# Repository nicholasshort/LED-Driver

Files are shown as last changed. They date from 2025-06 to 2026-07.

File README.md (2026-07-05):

# LED Driver

A USB-controlled addressable LED strip driver built to illuminate a model car display cabinet. The cabinet houses 500+ 1/43rd scale model cars across 4 vertical sections, each lit by two 120-LED strips (960 LEDs total). Any USB host can control the LEDs. For this appication, the garage includes a Raspberry Pi with a touchscreen running a web interface to send LED colour data.

<table>
  <tr>
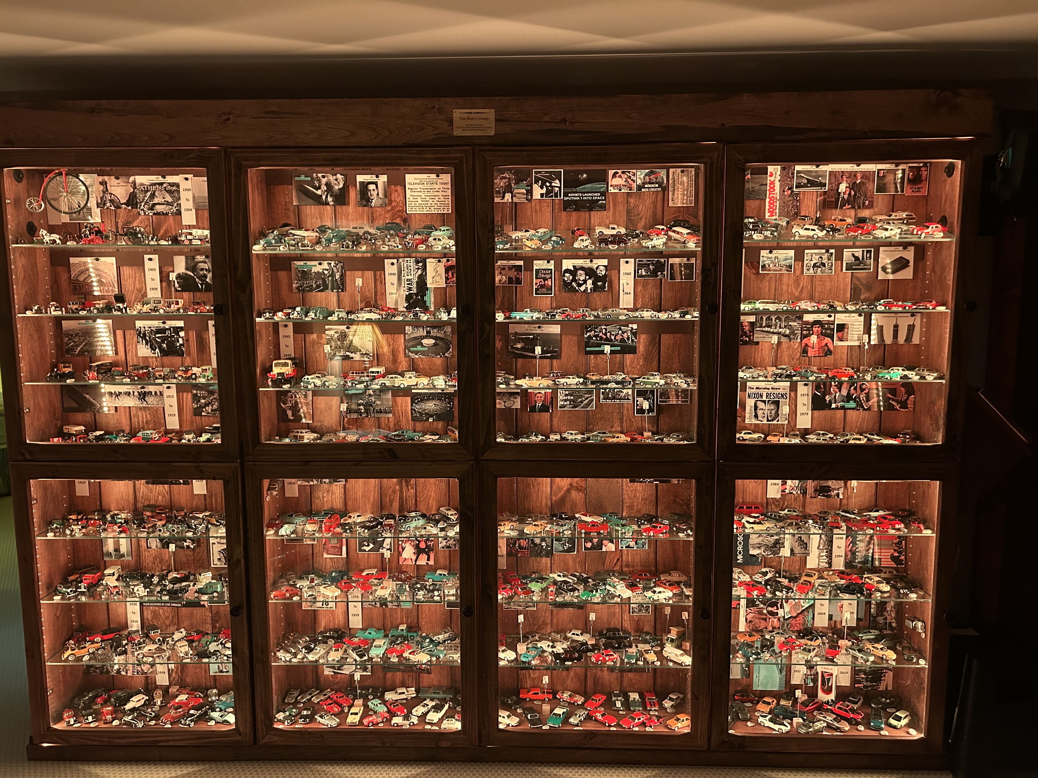
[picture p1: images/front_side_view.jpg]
    <td colspan="3"></td>
  </tr>
  <tr>
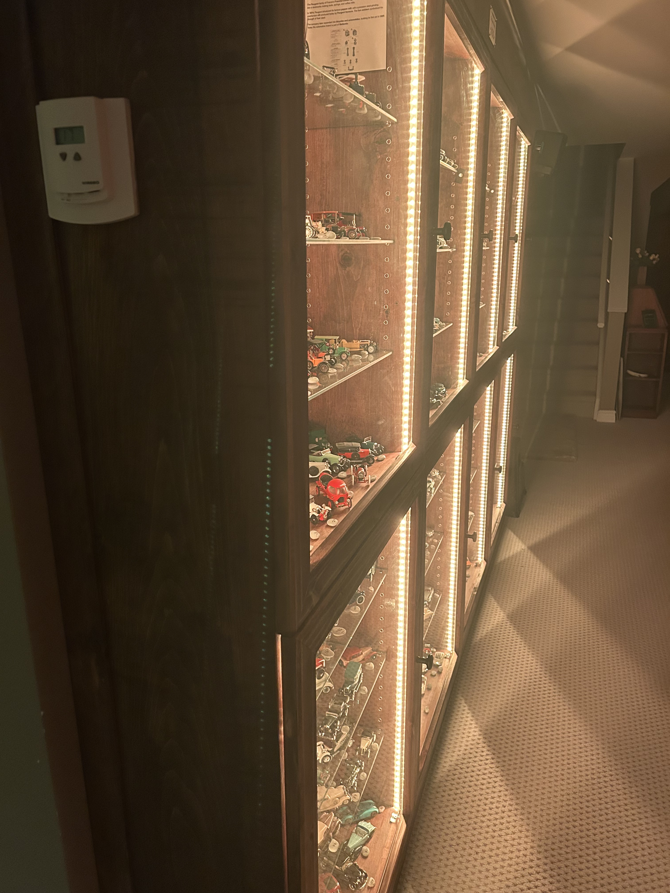
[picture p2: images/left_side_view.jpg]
    <td></td>
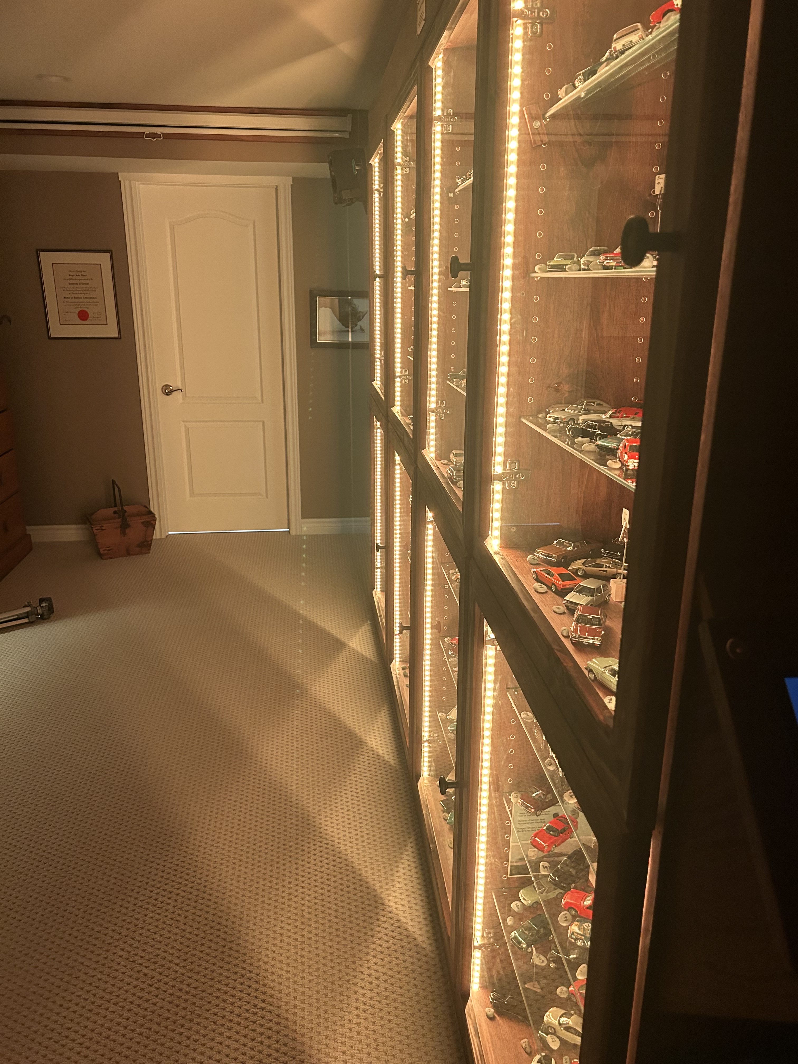
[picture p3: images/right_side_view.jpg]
    <td></td>
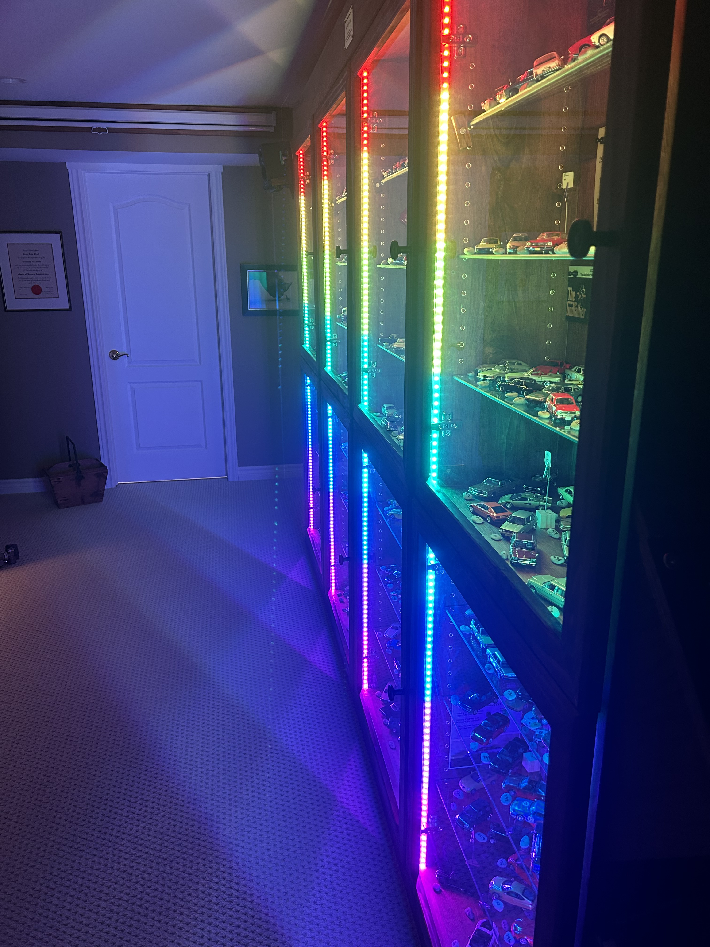
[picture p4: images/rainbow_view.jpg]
    <td></td>
  </tr>
</table>

## Hardware

- **MCU**: STM32F103RGT6 (Cortex-M3 @ 72 MHz, USB FS)
- **LEDs**: 8 × SK6812 addressable RGB strips (120 LEDs each)
- **Interface**: USB-C (CDC virtual COM port)
- **LED Control**: DMA-driven PWM for timing-critical waveform generation
- **PCB**: 4-layer, KiCad

## Repository layout

- `LED-DriverPCB/` — KiCad project (schematics, board, libraries)
- `LED-DriverPCB/Manufacturing/` — Gerbers, BOM, and pick-and-place files
- `LED-Driver-Firmware-RevB/` — STM32CubeIDE project
- `Garage-Files/` — Web control interface and startup audio

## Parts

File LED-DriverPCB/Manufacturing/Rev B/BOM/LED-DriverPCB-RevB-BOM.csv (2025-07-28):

Reference | Value | Footprint | Qty | JLCPCB Part #
H1 | MountingHole |  | 1
H2 | MountingHole |  | 1
H3 | MountingHole |  | 1
H4 | MountingHole |  | 1
H5 | MountingHole |  | 1
H6 | MountingHole |  | 1
H7 | MountingHole |  | 1
H8 | MountingHole |  | 1
J1 | Screw_Terminal_01x03 | 39303037:CONN_5569-03A4&slash_5_MOL | 1
J2 | Screw_Terminal_01x03 | 39303037:CONN_5569-03A4&slash_5_MOL | 1
J3 | Screw_Terminal_01x03 | 39303037:CONN_5569-03A4&slash_5_MOL | 1
J4 | Screw_Terminal_01x03 | 39303037:CONN_5569-03A4&slash_5_MOL | 1
J5 | Screw_Terminal_01x03 | 39303037:CONN_5569-03A4&slash_5_MOL | 1
J6 | Screw_Terminal_01x03 | 39303037:CONN_5569-03A4&slash_5_MOL | 1
J7 | Screw_Terminal_01x03 | 39303037:CONN_5569-03A4&slash_5_MOL | 1
J8 | Screw_Terminal_01x03 | 39303037:CONN_5569-03A4&slash_5_MOL | 1
J12 | Screw_Terminal_01x02 | 26013114:CONN_5569-02A_MOL | 1
J13 | Screw_Terminal_01x02 | 26013114:CONN_5569-02A_MOL | 1
J14 | Screw_Terminal_01x02 | 26013114:CONN_5569-02A_MOL | 1
J15 | Screw_Terminal_01x02 | 26013114:CONN_5569-02A_MOL | 1
J16 | Screw_Terminal_01x02 | 26013114:CONN_5569-02A_MOL | 1
J17 | Screw_Terminal_01x02 | 26013114:CONN_5569-02A_MOL | 1
J18 | Screw_Terminal_01x02 | 26013114:CONN_5569-02A_MOL | 1
J19 | Screw_Terminal_01x02 | 26013114:CONN_5569-02A_MOL | 1
J20 | Conn_ARM_SWD_TagConnect_TC2030 | Connector:Tag-Connect_TC2030-IDC-FP_2x03_P1.27mm_Vertical | 1
TP1 | TestPoint | TestPoint:TestPoint_Pad_1.0x1.0mm | 1
TP2 | TestPoint | TestPoint:TestPoint_Pad_1.0x1.0mm | 1
TP3 | TestPoint | TestPoint:TestPoint_Pad_1.0x1.0mm | 1
TP4 | TestPoint | TestPoint:TestPoint_Pad_1.0x1.0mm | 1
TP5 | TestPoint | TestPoint:TestPoint_Pad_1.0x1.0mm | 1
TP6 | TestPoint | TestPoint:TestPoint_Pad_1.0x1.0mm | 1
TP7 | TestPoint | TestPoint:TestPoint_Pad_1.0x1.0mm | 1
TP8 | TestPoint | TestPoint:TestPoint_Pad_1.0x1.0mm | 1
C3 | 100n | Capacitor_SMD:C_0603_1608Metric | 1 | C1590
C4 | 100n | Capacitor_SMD:C_0603_1608Metric | 1 | C1590
C5 | 100n | Capacitor_SMD:C_0603_1608Metric | 1 | C1590
C6 | 100n | Capacitor_SMD:C_0603_1608Metric | 1 | C1590
C7 | 100n | Capacitor_SMD:C_0603_1608Metric | 1 | C1590
C8 | 100n | Capacitor_SMD:C_0603_1608Metric | 1 | C1590
C10 | 100n | Capacitor_SMD:C_0603_1608Metric | 1 | C1590
C16 | 100n | Capacitor_SMD:C_0603_1608Metric | 1 | C1590
U3 | AMS1117-3.3 | Package_TO_SOT_SMD:SOT-223-3_TabPin2 | 1 | C6186
U4 | USBLC6-2SC6 | Package_TO_SOT_SMD:SOT-23-6 | 1 | C7519
U5 | STM32F103RGTx | Package_QFP:LQFP-64_10x10mm_P0.5mm | 1 | C8317
R6 | 1k | Resistor_SMD:R_0402_1005Metric | 1 | C11702
C9 | 10u | Capacitor_SMD:C_0805_2012Metric | 1 | C15850
C11 | 10u | Capacitor_SMD:C_0805_2012Metric | 1 | C15850
R8 | 0R | Resistor_SMD:R_0603_1608Metric | 1 | C21189
R9 | 0R | Resistor_SMD:R_0603_1608Metric | 1 | C21189
R10 | 0R | Resistor_SMD:R_0603_1608Metric | 1 | C21189
R11 | 0R | Resistor_SMD:R_0603_1608Metric | 1 | C21189
R12 | 0R | Resistor_SMD:R_0603_1608Metric | 1 | C21189
R13 | 0R | Resistor_SMD:R_0603_1608Metric | 1 | C21189
R14 | 0R | Resistor_SMD:R_0603_1608Metric | 1 | C21189
R15 | 0R | Resistor_SMD:R_0603_1608Metric | 1 | C21189
R5 | 1.5k | Resistor_SMD:R_0603_1608Metric | 1 | C22843
R2 | 5.1k | Resistor_SMD:R_0603_1608Metric | 1 | C23186
R3 | 5.1k | Resistor_SMD:R_0603_1608Metric | 1 | C23186
R1 | 10k | Resistor_SMD:R_0603_1608Metric | 1 | C25804
R4 | 10k | Resistor_SMD:R_0603_1608Metric | 1 | C25804
R7 | 10k | Resistor_SMD:R_0603_1608Metric | 1 | C25804
C12 | 22u | Capacitor_SMD:C_0805_2012Metric | 1 | C45783
C1 | 10p | Capacitor_SMD:C_0402_1005Metric | 1 | C161145
C2 | 10p | Capacitor_SMD:C_0402_1005Metric | 1 | C161145
J9 | USB_C_Receptacle_USB2.0_16P | Connector_USB:USB_C_Receptacle_HRO_TYPE-C-31-M-12 | 1 | C165948
X1 | 8MHz | Crystal:Crystal_SMD_3225-4Pin_3.2x2.5mm | 1 | C400090
U1 | 74AHCT244 | Package_SO:TSSOP-20_4.4x6.5mm_P0.65mm | 1 | C484743
D1 | LED | LED_SMD:LED_0603_1608Metric | 1 | C5123548

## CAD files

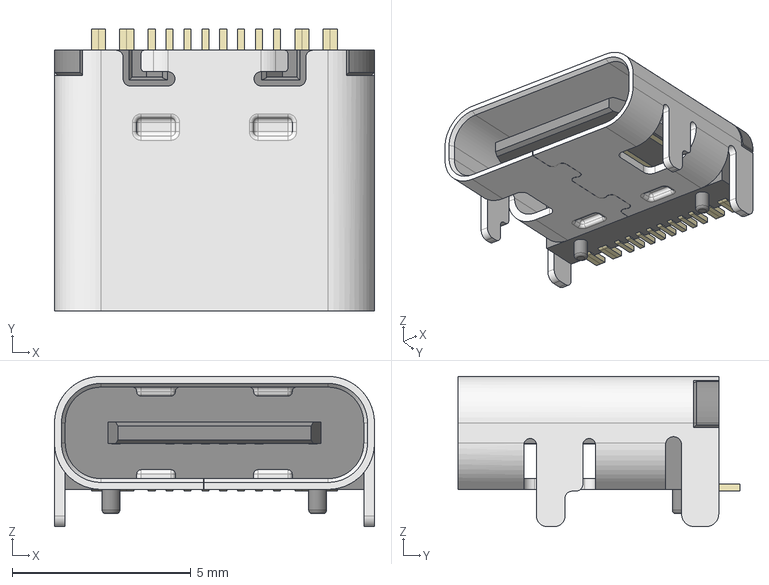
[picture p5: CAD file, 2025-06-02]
LED-DriverPCB/Components/Miscellaneous 3D Models/HRO_TYPE-C-31-M-12.step
8.95 x 7.90 x 4.20 mm

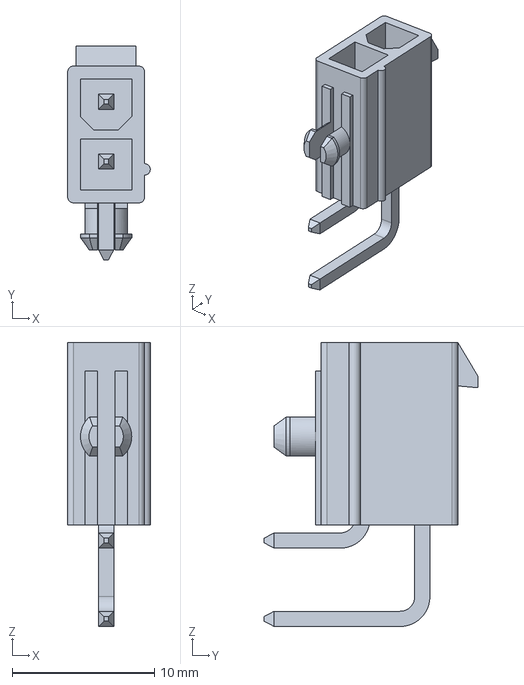
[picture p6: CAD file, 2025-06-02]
LED-DriverPCB/Components/26013114/026013114.stp
5.80 x 15.0 x 19.9 mm

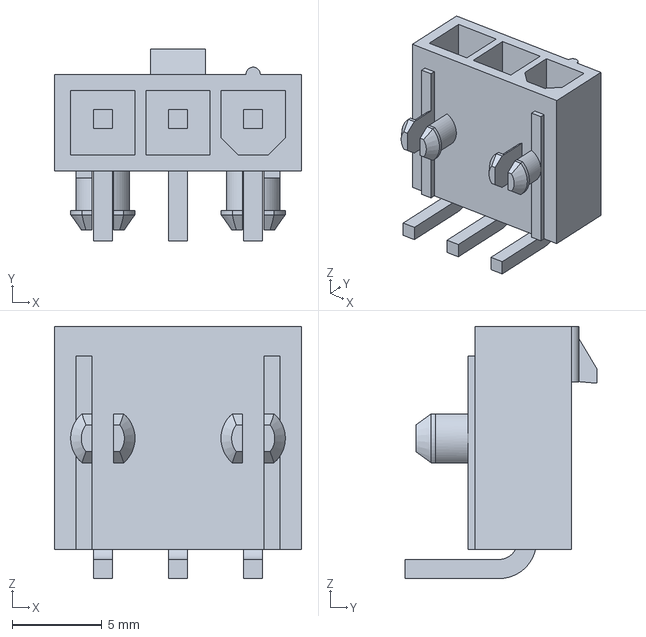
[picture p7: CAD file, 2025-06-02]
LED-DriverPCB/Components/39303037/039303037.stp
13.8 x 10.7 x 14.1 mm

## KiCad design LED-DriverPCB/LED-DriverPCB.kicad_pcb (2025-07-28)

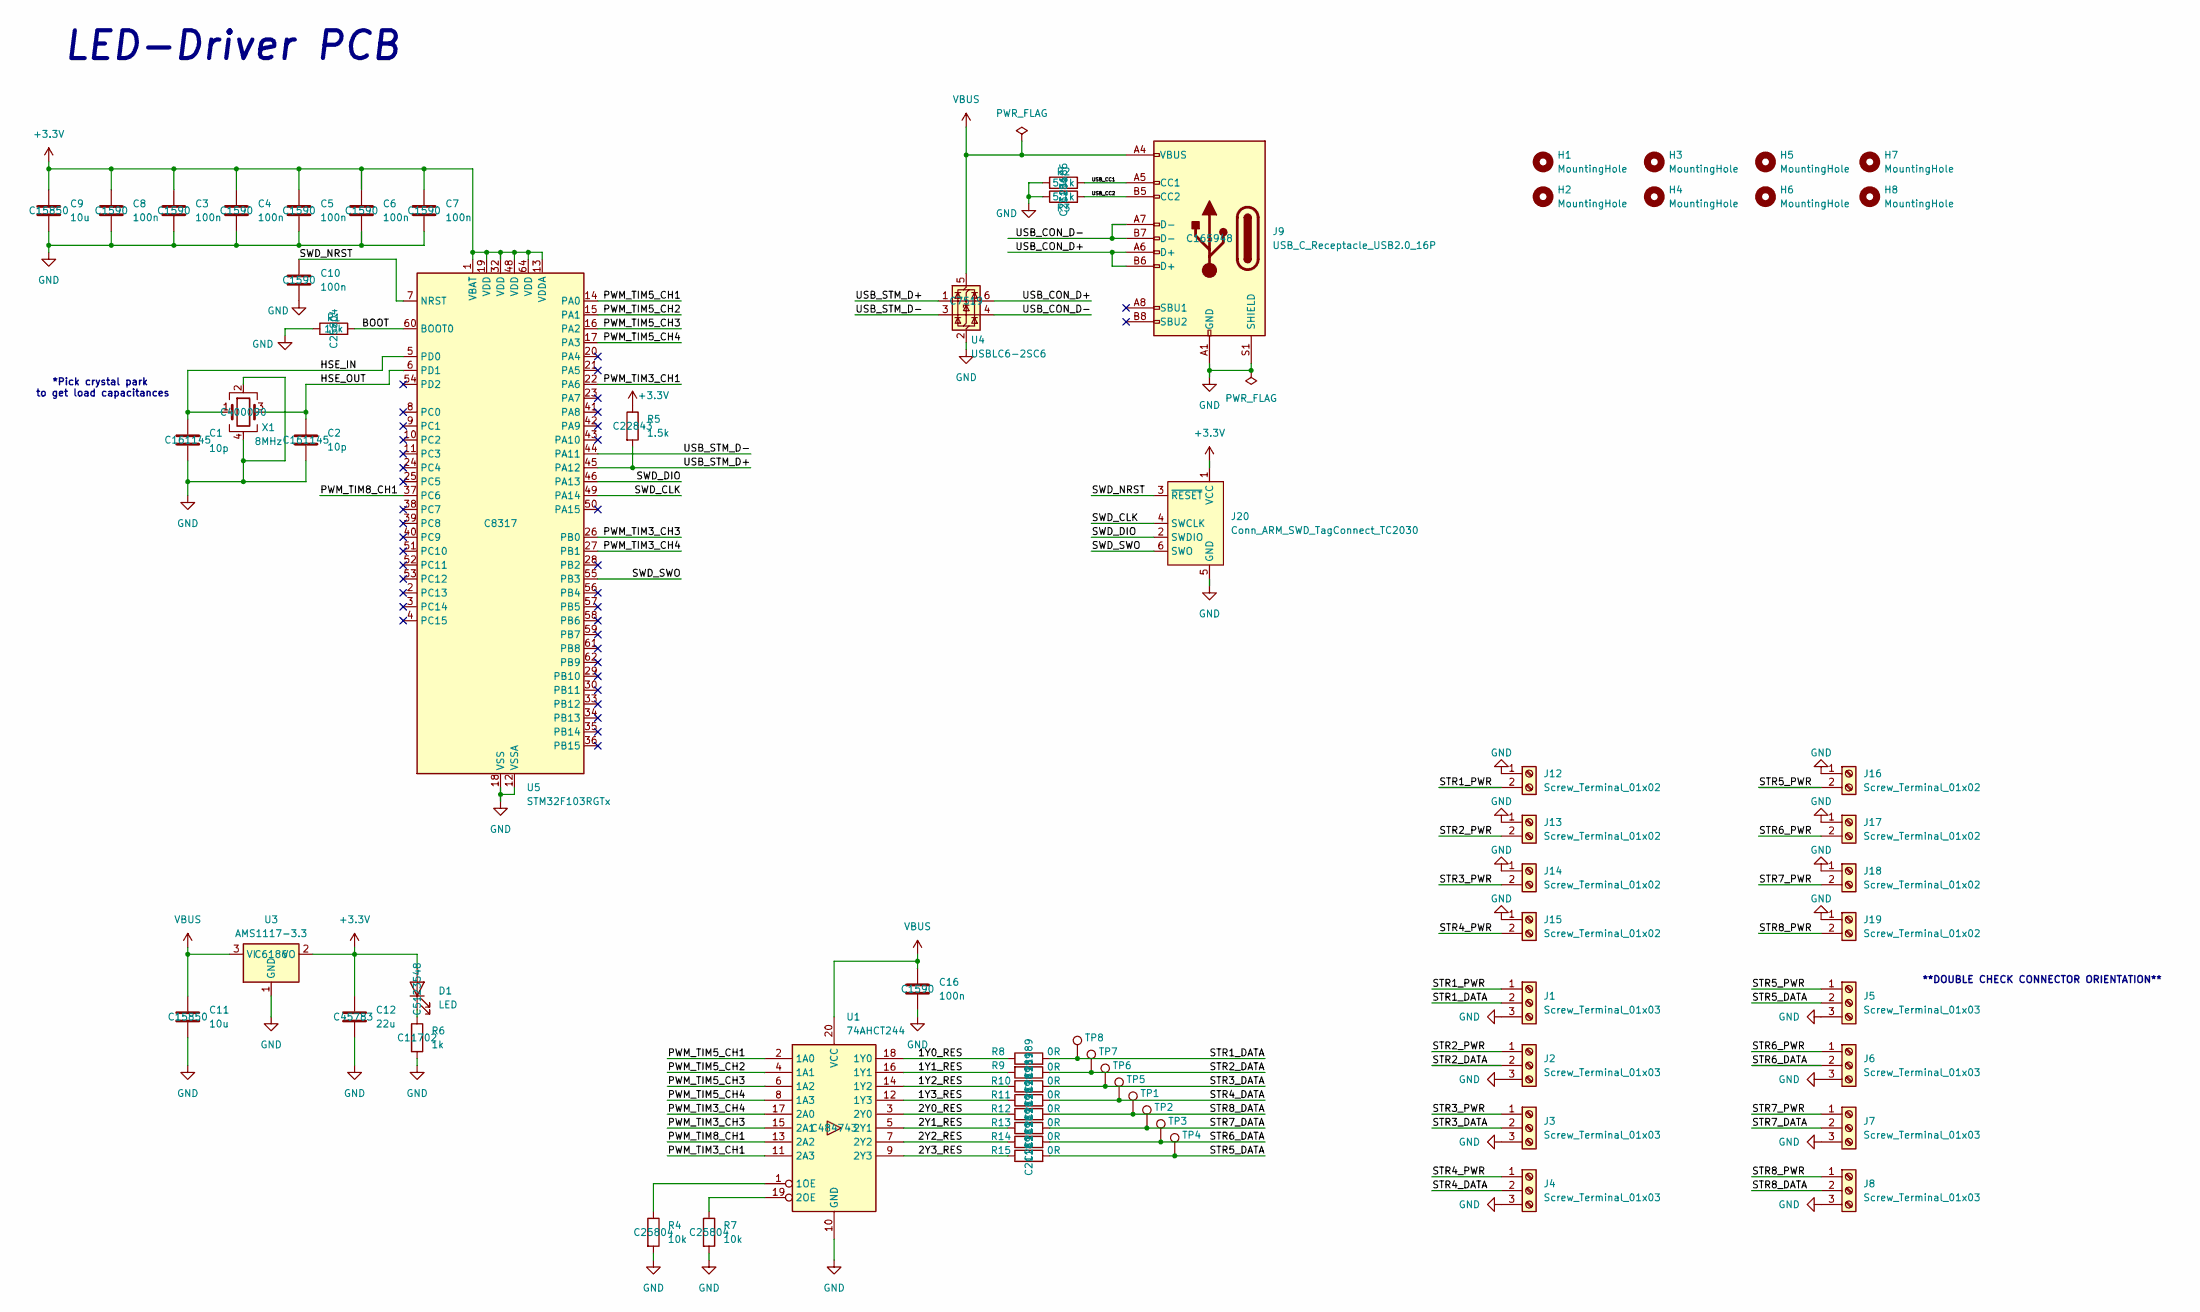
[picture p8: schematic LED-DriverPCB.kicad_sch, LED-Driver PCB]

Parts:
C1, C2: 10p; C_0402_1005Metric; JLCPCB Part # C161145
C3, C4, C5, C6, C7, C8, C10, C16: 100n; C_0603_1608Metric; JLCPCB Part # C1590
C9, C11: 10u; C_0805_2012Metric; JLCPCB Part # C15850
C12: 22u; C_0805_2012Metric; JLCPCB Part # C45783
D1: LED; LED_0603_1608Metric; JLCPCB Part # C5123548
H1, H2, H3, H4, H5, H6, H7, H8: MountingHole
J1, J2, J3, J4, J5, J6, J7, J8: Screw_Terminal_01x03; CONN_5569-03A4&slash_5_MOL
J9: USB_C_Receptacle_USB2.0_16P; USB_C_Receptacle_HRO_TYPE-C-31-M-12; JLCPCB Part # C165948
J12, J13, J14, J15, J16, J17, J18, J19: Screw_Terminal_01x02; CONN_5569-02A_MOL
J20: Conn_ARM_SWD_TagConnect_TC2030; Tag-Connect_TC2030-IDC-FP_2x03_P1.27mm_Vertical
R1, R4, R7: 10k; R_0603_1608Metric; JLCPCB Part # C25804
R2, R3: 5.1k; R_0603_1608Metric; JLCPCB Part # C23186
R5: 1.5k; R_0603_1608Metric; JLCPCB Part # C22843
R6: 1k; R_0402_1005Metric; JLCPCB Part # C11702
R8, R9, R10, R11, R12, R13, R14, R15: 0R; R_0603_1608Metric; JLCPCB Part # C21189
TP1, TP2, TP3, TP4, TP5, TP6, TP7, TP8: TestPoint; TestPoint_Pad_1.0x1.0mm
U1: 74AHCT244; TSSOP-20_4.4x6.5mm_P0.65mm; JLCPCB Part # C484743
U3: AMS1117-3.3; SOT-223-3_TabPin2; JLCPCB Part # C6186
U4: USBLC6-2SC6; SOT-23-6; JLCPCB Part # C7519
U5: STM32F103RGTx; LQFP-64_10x10mm_P0.5mm; JLCPCB Part # C8317
X1: 8MHz; Crystal_SMD_3225-4Pin_3.2x2.5mm; JLCPCB Part # C400090

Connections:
+3.3V: C3.1, C4.1, C5.1, C6.1, C7.1, C8.1, C9.1, C12.1, D1.2 (A), J20.1 (VCC), R5.1, U3.2 (VO), U5.1 (VBAT), U5.13 (VDDA), U5.19 (VDD), U5.32 (VDD), U5.48 (VDD), U5.64 (VDD)
/1Y0_RES: R8.1, U1.18 (1Y0)
/1Y1_RES: R9.2, U1.16 (1Y1)
/1Y2_RES: R10.1, U1.14 (1Y2)
/1Y3_RES: R11.1, U1.12 (1Y3)
/2Y0_RES: R12.1, U1.3 (2Y0)
/2Y1_RES: R13.1, U1.5 (2Y1)
/2Y2_RES: R14.1, U1.7 (2Y2)
/2Y3_RES: R15.1, U1.9 (2Y3)
/BOOT: R1.2, U5.60 (BOOT0)
/HSE_IN: C1.1, U5.5 (PD0), X1.1
/HSE_OUT: C2.1, U5.6 (PD1), X1.3
/PWM_TIM3_CH1: U1.11 (2A3), U5.22 (PA6)
/PWM_TIM3_CH3: U1.15 (2A1), U5.26 (PB0)
/PWM_TIM3_CH4: U1.17 (2A0), U5.27 (PB1)
/PWM_TIM5_CH1: U1.2 (1A0), U5.14 (PA0)
/PWM_TIM5_CH2: U1.4 (1A1), U5.15 (PA1)
/PWM_TIM5_CH3: U1.6 (1A2), U5.16 (PA2)
/PWM_TIM5_CH4: U1.8 (1A3), U5.17 (PA3)
/PWM_TIM8_CH1: U1.13 (2A2), U5.37 (PC6)
/STR1_DATA: J1.2, R8.2, TP8.1
/STR1_PWR: J1.1, J12.2
/STR2_DATA: J2.2, R9.1, TP7.1
/STR2_PWR: J2.1, J13.2
/STR3_DATA: J3.2, R10.2, TP6.1
/STR3_PWR: J3.1, J14.2
/STR4_DATA: J4.2, R11.2, TP5.1
/STR4_PWR: J4.1, J15.2
/STR5_DATA: J5.2, R15.2, TP4.1
/STR5_PWR: J5.1, J16.2
/STR6_DATA: J6.2, R14.2, TP3.1
/STR6_PWR: J6.1, J17.2
/STR7_DATA: J7.2, R13.2, TP2.1
/STR7_PWR: J7.1, J18.2
/STR8_DATA: J8.2, R12.2, TP1.1
/STR8_PWR: J8.1, J19.2
/SWD_CLK: J20.4 (SWCLK), U5.49 (PA14)
/SWD_DIO: J20.2 (SWDIO), U5.46 (PA13)
/SWD_NRST: C10.1, J20.3 (~RESET), U5.7 (NRST)
/SWD_SWO: J20.6 (SWO), U5.55 (PB3)
/USB_CC1: J9.A5 (CC1), R2.2
/USB_CC2: J9.B5 (CC2), R3.2
/USB_CON_D+: J9.A6 (D+), J9.B6 (D+), U4.6 (I/O1)
/USB_CON_D-: J9.A7 (D-), J9.B7 (D-), U4.4 (I/O2)
/USB_STM_D+: R5.2, U4.1 (I/O1), U5.45 (PA12)
/USB_STM_D-: U4.3 (I/O2), U5.44 (PA11)
GND: C1.2, C2.2, C3.2, C4.2, C5.2, C6.2, C7.2, C8.2, C9.2, C10.2, C11.2, C12.2, C16.2, J1.3, J2.3, J3.3, J4.3, J5.3, J6.3, J7.3, J8.3, J9.A1 (GND), J9.A12 (GND), J9.B1 (GND), J9.B12 (GND), J9.S1 (SHIELD), J12.1, J13.1, J14.1, J15.1, J16.1, J17.1, J18.1, J19.1, J20.5 (GND), R1.1, R2.1, R3.1, R4.2, R6.2, R7.2, U1.10 (GND), U3.1 (GND), U4.2 (GND), U5.12 (VSSA), U5.18 (VSS), U5.31 (VSS), U5.47 (VSS), U5.63 (VSS), X1.2, X1.4
unnamed: D1.1 (K), R6.1
unnamed: R4.1, U1.1 (1OE)
unnamed: R7.1, U1.19 (2OE)
VBUS: C11.1, C16.1, J9.A4 (VBUS), J9.A9 (VBUS), J9.B4 (VBUS), J9.B9 (VBUS), U1.20 (VCC), U3.3 (VI), U4.5 (VBUS)

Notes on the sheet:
LED-Driver PCB
*Pick crystal park to get load capacitances
**DOUBLE CHECK CONNECTOR ORIENTATION**

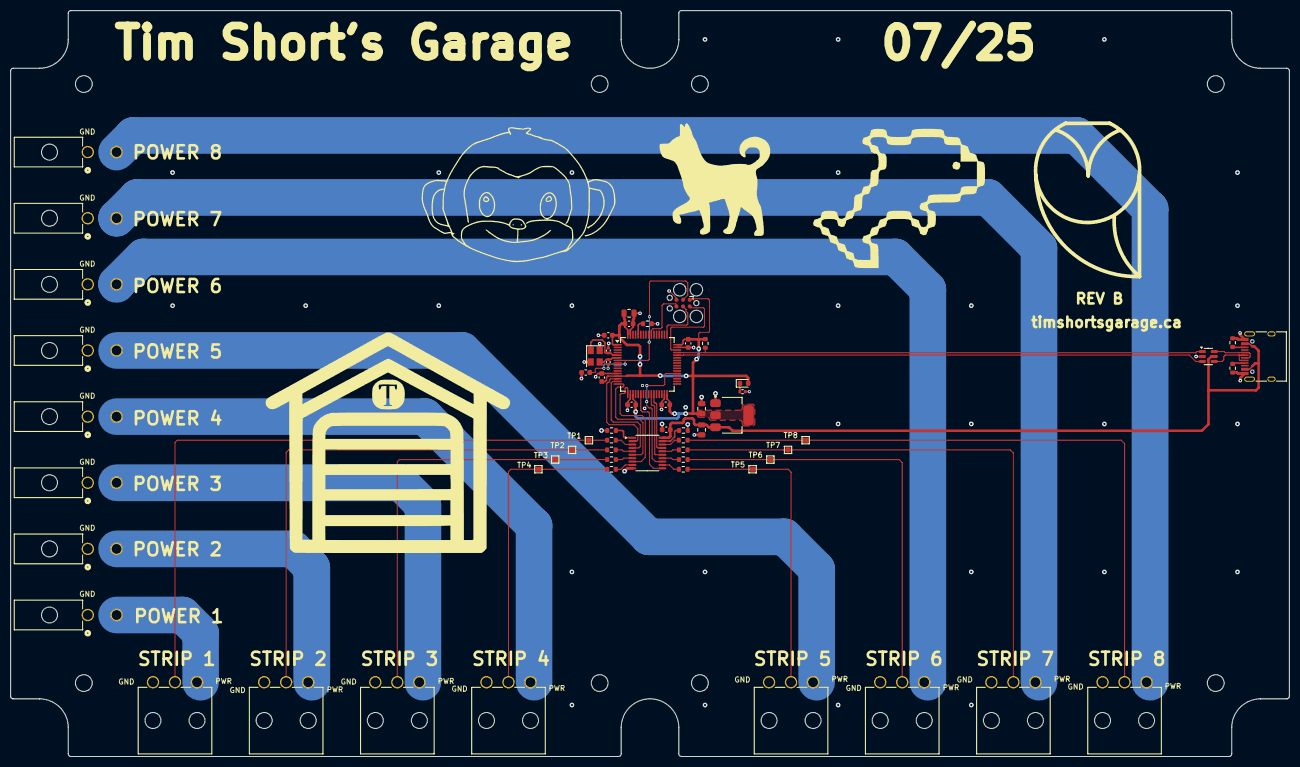
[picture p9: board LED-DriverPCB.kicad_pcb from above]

Board: 4 copper layers, 244.0 x 142.3 mm, 68 parts (0 on the bottom side), 51 nets.

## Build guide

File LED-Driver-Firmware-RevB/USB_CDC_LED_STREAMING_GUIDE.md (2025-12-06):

# USB CDC LED Frame Streaming Protocol - Integration Guide

## Overview

This implementation provides a complete USB CDC-based LED frame streaming system for driving 8 parallel SK6812 LED strips (120 LEDs each) from a Raspberry Pi host to an STM32F1 microcontroller.

**Key Features:**
- 30 FPS RGB LED frame streaming over USB CDC Virtual COM Port
- Robust framing protocol with checksum validation
- Double-buffered frame reception (no tearing)
- Non-blocking USB receive handling
- Streaming parser handles arbitrary USB packet chunking
- Total throughput: ~864 KB/s (2880 bytes × 30 fps + protocol overhead)

---

## Architecture

### Hardware
- **MCU:** STM32F103 @ 72 MHz
- **USB:** Full Speed Device (12 Mbps), CDC class
- **LEDs:** 8 strips × 120 LEDs × 3 bytes (RGB) = 2880 bytes per frame
- **Host:** Raspberry Pi (or any Linux system with USB)

### Software Components

#### STM32 Firmware
1. **usb_protocol.c/h** - Protocol parser and double buffering
2. **usbd_cdc_if.c** - USB CDC receive callback integration
3. **main.c** - Main loop with LED update logic
4. **LEDStrip_Manager** - Existing LED driver (your implementation)
5. **SK6812-LEDStrip** - Existing SK6812 driver (your implementation)

#### Raspberry Pi Host
1. **host_send_led_frames.py** - Python script for streaming frames at 30 FPS

---

## Protocol Specification

### Frame Structure

Every frame consists of:
1. **Header (9 bytes)** - Fixed format
2. **Payload (2880 bytes)** - RGB data for all LEDs

### Header Format

```c
#pragma pack(push, 1)
typedef struct {
    uint8_t  sof1;       // 0xAA - Start of frame marker
    uint8_t  sof2;       // 0x55 - Start of frame marker
    uint8_t  version;    // 0x01 - Protocol version
    uint8_t  type;       // 0x01 - Frame type (full LED frame)
    uint16_t length;     // 2880 - Payload length (little endian)
    uint16_t frame_id;   // Frame counter (little endian, wraps at 65535)
    uint8_t  checksum;   // 8-bit sum of payload bytes mod 256
} frame_hdr_t;
#pragma pack(pop)
```

**Total frame size:** 9 + 2880 = 2889 bytes

### Payload Layout

The 2880-byte payload contains RGB data for all LEDs:

```
Strip 0: [LED 0..119] = R,G,B, R,G,B, ... (360 bytes)
Strip 1: [LED 0..119] = R,G,B, R,G,B, ... (360 bytes)
...
Strip 7: [LED 0..119] = R,G,B, R,G,B, ... (360 bytes)
```

**Memory mapping:**
- Strip N, LED M: `payload[N * 360 + M * 3 + {0=R, 1=G, 2=B}]`

### Checksum Calculation

```c
uint8_t checksum = 0;
for (int i = 0; i < 2880; i++) {
    checksum += payload[i];
}
checksum = checksum & 0xFF;
```

---

## STM32 Implementation Details

### State Machine

The protocol parser implements a streaming state machine in `usb_protocol.c`:

```
RX_WAIT_SOF1 → Wait for 0xAA
     ↓
RX_WAIT_SOF2 → Wait for 0x55
     ↓
RX_READ_HEADER → Read remaining 7 header bytes
     ↓
RX_READ_PAYLOAD → Read 2880 payload bytes into pending_frame
     ↓
Validate checksum → Swap buffers if valid → RX_WAIT_SOF1
```

**Key features:**
- Handles arbitrary USB packet chunking (e.g., 64-byte CDC packets)
- Validates SOF bytes, version, type, and length
- Computes and verifies 8-bit checksum
- Atomically swaps double buffers using interrupt disable/enable

### Double Buffering

Two 2880-byte buffers:
- **active_frame** - Currently displayed (read by main loop)
- **pending_frame** - Being written by USB receive (write by parser)

When a valid frame is received:
1. Checksum is validated
2. Pointers are swapped atomically (`__disable_irq()` / `__enable_irq()`)
3. `new_frame_ready` flag is set
4. Main loop detects flag and sends active_frame to LEDs

This prevents tearing and ensures the main loop always sees complete, validated frames.

### USB Receive Flow

```c
// In usbd_cdc_if.c
static int8_t CDC_Receive_FS(uint8_t* Buf, uint32_t *Len)
{
    // Feed bytes to streaming parser (non-blocking)
    protocol_feed_bytes(Buf, *Len);

    // Re-arm USB endpoint immediately
    USBD_CDC_SetRxBuffer(&hUsbDeviceFS, &Buf[0]);
    USBD_CDC_ReceivePacket(&hUsbDeviceFS);

    return USBD_OK;
}
```

**Critical:** No blocking operations in `CDC_Receive_FS()`. LED updates happen in main loop.

### Main Loop Integration

```c
// In main.c
while (1)
{
    if (protocol_new_frame_ready())
    {
        const uint8_t *frame = protocol_get_active_frame();

        // Copy frame data to LED driver buffers
        for (uint8_t strip = 0; strip < 8; strip++)
        {
            for (uint16_t led = 0; led < 120; led++)
            {
                uint16_t offset = strip * 360 + led * 3;
                SK6812_SetColour(handle, led,
                    frame[offset + 0],  // R
                    frame[offset + 1],  // G
                    frame[offset + 2]); // B
            }
        }

        // Send to LEDs (blocking)
        for (uint8_t strip = 0; strip < 8; strip++)
            SK6812_Update(LEDStrip_Manager_Get_Strip_Handle(strip));

        protocol_ack_frame();
    }

    HAL_Delay(1);
}
```

---

## Raspberry Pi Host Implementation

### Requirements

```bash
pip install pyserial
```

### Running the Script

```bash
# Default device (/dev/ttyACM0)
python3 host_send_led_frames.py

# Custom device
python3 host_send_led_frames.py /dev/ttyACM1
```

### Animation Modes

Edit `animation_mode` variable in `main()`:

- `'rainbow'` - Moving rainbow pattern
- `'chaser'` - Colored dots chasing down each strip
- `'solid'` - Breathing blue effect

### Frame Generation

The Python script:
1. Generates 2880-byte RGB payload
2. Calculates checksum
3. Builds 9-byte header with `struct.pack('<BBBBHHB', ...)`
4. Sends header + payload over serial
5. Sleeps to maintain ~30 FPS

**Actual timing:** The script compensates for frame generation and transmission time, targeting 30 FPS average.

---

## Files Modified/Created

### New Files
- `Core/Inc/usb_protocol.h` - Protocol API and constants
- `Core/Src/usb_protocol.c` - Parser and buffer management
- `host_send_led_frames.py` - Raspberry Pi sender script

### Modified Files
- `USB_DEVICE/App/usbd_cdc_if.c` - Added `protocol_feed_bytes()` call in `CDC_Receive_FS()`
- `Core/Src/main.c` - Added protocol init and main loop LED update logic

### Unchanged (Existing LED Drivers)
- `Core/Inc/LEDStrip_Manager.h`
- `Core/Src/LEDStrip_Manager.c`
- `Core/Inc/SK6812-LEDStrip.h`
- `Core/Src/SK6812-LEDStrip.c`

---

## Build & Flash Instructions

### STM32 Side

1. **Add source files to build:**
   - Ensure `usb_protocol.c` is compiled
   - Include paths should have `Core/Inc`

2. **Build in STM32CubeIDE or Make:**
   ```bash
   make clean
   make -j8
   ```

3. **Flash to STM32:**
   ```bash
   # Using ST-Link
   st-flash write build/LED-Driver-Firmware-RevB.bin 0x8000000

   # Or use STM32CubeIDE upload
   ```

4. **Connect USB cable** between Raspberry Pi and STM32 USB port

### Raspberry Pi Side

1. **Check device appears:**
   ```bash
   ls -l /dev/ttyACM*
   # Should show /dev/ttyACM0 (or ACM1, etc.)
   ```

2. **Set permissions (if needed):**
   ```bash
   sudo chmod 666 /dev/ttyACM0
   # Or add user to dialout group:
   sudo usermod -a -G dialout $USER
   # Then log out and back in
   ```

3. **Run the script:**
   ```bash
   python3 host_send_led_frames.py
   ```

---

## Performance Characteristics

### Throughput
- **Frame size:** 2889 bytes (9 header + 2880 payload)
- **Frame rate:** 30 FPS
- **Data rate:** ~86.7 KB/s (693 kbps)
- **USB CDC bandwidth:** 12 Mbps (plenty of headroom)

### Latency
- **USB packet latency:** ~1 ms per 64-byte packet
- **Frame transmission:** ~45 packets × 1 ms = ~45 ms worst case
- **Typical latency:** 15-30 ms (buffering + transmission)

### LED Update Time
- **Per strip:** ~3 ms (120 LEDs × 24 bits × 1.25 µs/bit)
- **8 strips sequentially:** ~24 ms
- **Total frame time:** ~30-40 ms (USB RX + LED TX)

**Result:** System comfortably achieves 30 FPS with headroom for occasional delays.

---

## Debugging Tips

### STM32 Side

1. **Check protocol stats:**
   ```c
   protocol_stats_t stats;
   protocol_get_stats(&stats);
   // Examine frames_received, frames_dropped, sync_errors, length_errors
   ```

2. **Add debug output (optional):**
   - Use `CDC_Transmit_FS()` to send debug messages back to host
   - Be careful not to block USB receive

3. **Verify buffer alignment:**
   - Frame buffers are 2880 bytes each
   - Check `active_frame` and `pending_frame` addresses

### Host Side

1. **Monitor serial errors:**
   ```python
   # Check ser.in_waiting, ser.out_waiting
   # Look for SerialException
   ```

2. **Verify checksum:**
   ```python
   calculated = sum(payload) & 0xFF
   print(f"Checksum: {calculated}")
   ```

3. **Test with solid colors first:**
   - Set `animation_mode = 'solid'`
   - Easier to verify correctness

### Common Issues

| Symptom | Likely Cause | Solution |
|---|---|---|
| No LEDs lighting | Protocol init not called | Check `protocol_init()` in main.c |
| Random colors/flickering | Checksum errors | Check USB cable quality, verify checksum calc |
| Slow frame rate | LED update blocking too long | Optimize LED driver, check for delays |
| No USB device on Pi | USB not enumerated | Check USB cable, verify STM32 USB config |
| Parser stuck | SOF bytes not aligned | Reset parser state, check frame structure |

---

## Extending the Protocol

### Adding New Frame Types

1. **Define new type constant:**
   ```c
   #define FRAME_TYPE_PARTIAL 0x02
   ```

2. **Update parser to handle new type:**
   ```c
   case RX_READ_HEADER:
       if (rx_header.type == FRAME_TYPE_PARTIAL) {
           // Handle partial update
       }
       break;
   ```

3. **Update Python script:**
   ```python
   FRAME_TYPE_PARTIAL = 0x02
   ```

### Adding Compression

Could implement simple RLE or delta encoding:
- Type 0x01: Full frame
- Type 0x02: Delta from previous frame
- Type 0x03: RLE compressed

Would reduce bandwidth for static or slow-changing content.

### Adding Acknowledgments

STM32 could send back ACK frames using `CDC_Transmit_FS()`:
```c
uint8_t ack[] = {0xAA, 0xAC, frame_id & 0xFF, frame_id >> 8};
CDC_Transmit_FS(ack, 4);
```

Host could verify reception and retransmit if needed.

---

## License & Credits

- **STM32 HAL:** STMicroelectronics (see license headers)
- **USB CDC:** Generated by STM32CubeMX
- **Protocol & Integration:** Custom implementation (2025)
- **LED Drivers:** SK6812-LEDStrip, LEDStrip_Manager (your existing code)

---

## Summary

This implementation provides a production-ready USB CDC streaming protocol for high-framerate LED control. The key design decisions:

1. **Non-blocking USB receive** - Parser is fast, LED updates happen in main loop
2. **Double buffering** - Eliminates tearing, validates before display
3. **Streaming parser** - Handles arbitrary packet chunking robustly
4. **Simple framing** - SOF bytes for sync, checksum for validation
5. **Host-driven timing** - Raspberry Pi controls frame rate, STM32 just displays

The system is extensible and can be adapted for different LED counts, frame rates, or protocol enhancements.

**Enjoy your 30 FPS LED light show!** 🎨✨

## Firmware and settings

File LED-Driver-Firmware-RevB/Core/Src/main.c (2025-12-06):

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
/* Includes ------------------------------------------------------------------*/
#include "main.h"
#include "usb_device.h"

/* USER CODE BEGIN Includes */
#include "usb_protocol.h"
#include "LEDStrip_Manager.h"
#include "SK6812-LEDStrip.h"
/* USER CODE END Includes */

TIM_HandleTypeDef htim3;
TIM_HandleTypeDef htim5;
TIM_HandleTypeDef htim8;
DMA_HandleTypeDef hdma_tim3_ch1_trig;
DMA_HandleTypeDef hdma_tim3_ch3;
DMA_HandleTypeDef hdma_tim3_ch4_up;
DMA_HandleTypeDef hdma_tim5_ch1;
DMA_HandleTypeDef hdma_tim5_ch2;
DMA_HandleTypeDef hdma_tim5_ch3_up;
DMA_HandleTypeDef hdma_tim5_ch4_trig;
DMA_HandleTypeDef hdma_tim8_ch1;

void SystemClock_Config(void);
static void MX_GPIO_Init(void);
static void MX_DMA_Init(void);
static void MX_TIM3_Init(void);
static void MX_TIM5_Init(void);
static void MX_TIM8_Init(void);
/**
  * @brief  The application entry point.
  * @retval int
  */
int main(void)
{

  /* MCU Configuration--------------------------------------------------------*/

  /* Reset of all peripherals, Initializes the Flash interface and the Systick. */
  HAL_Init();

  /* Configure the system clock */
  SystemClock_Config();

  /* Initialize all configured peripherals */
  MX_GPIO_Init();
  MX_DMA_Init();
  MX_TIM3_Init();
  MX_TIM5_Init();
  MX_TIM8_Init();
  MX_USB_DEVICE_Init();
  /* USER CODE BEGIN 2 */
	LEDStrip_Manager_Init();

	// Initialize USB protocol parser
	protocol_init();
  /* USER CODE END 2 */

  /* Infinite loop */
  /* USER CODE BEGIN WHILE */
  while (1)
  {
    /* USER CODE END WHILE */

    /* USER CODE BEGIN 3 */

    // Check if a new LED frame is ready from USB
    if (protocol_new_frame_ready())
    {
        // Get pointer to active frame buffer
        const uint8_t *frame = protocol_get_active_frame();

        // Frame layout: 8 strips * 120 LEDs * 3 bytes (RGB)
        // Each strip: 360 bytes (120 LEDs * 3)
        // Total: 2880 bytes
        //
        // Byte layout in frame buffer:
        // Strip 0: frame[0..359]     - LEDs 0..119 as R,G,B triplets
        // Strip 1: frame[360..719]   - LEDs 0..119 as R,G,B triplets
        // ...
        // Strip 7: frame[2520..2879] - LEDs 0..119 as R,G,B triplets

        // Update all 8 LED strips
        for (uint8_t strip = 0; strip < LEDSTRIP_COUNT; strip++)
        {
            SK6812_HandleTypeDef *strip_handle = LEDStrip_Manager_Get_Strip_Handle(strip);

            // Calculate offset into frame buffer for this strip
            uint16_t strip_offset = strip * LEDS_PER_STRIP * BYTES_PER_LED;

            // Update each LED in this strip
            for (uint16_t led = 0; led < LEDS_PER_STRIP; led++)
            {
                uint16_t led_offset = strip_offset + (led * BYTES_PER_LED);

                // Extract RGB values from frame (frame format is R,G,B)
                uint8_t r = frame[led_offset + 0];
                uint8_t g = frame[led_offset + 1];
                uint8_t b = frame[led_offset + 2];

                // Set the color (SK6812_SetColour takes R, G, B)
                SK6812_SetColour(strip_handle, led, r, g, b);
            }
        }

        // Send updated data to all LED strips
        // Note: This is blocking and will take time proportional to number of LEDs
        for (uint8_t strip = 0; strip < LEDSTRIP_COUNT; strip++)
        {
            SK6812_HandleTypeDef *strip_handle = LEDStrip_Manager_Get_Strip_Handle(strip);
            SK6812_Update(strip_handle);
        }

        // Acknowledge that we've processed this frame
        protocol_ack_frame();
    }

    // Small delay to prevent tight spinning (optional)
    HAL_Delay(1);
  }
  /* USER CODE END 3 */
}

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


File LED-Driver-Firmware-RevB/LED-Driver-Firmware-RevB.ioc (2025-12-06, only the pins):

Mcu.UserName=STM32F103RGTx
PA0-WKUP.Signal=S_TIM5_CH1
PA1.Signal=S_TIM5_CH2
PA11.Signal=USB_DM
PA12.Signal=USB_DP
PA13.Signal=SYS_JTMS-SWDIO
PA14.Signal=SYS_JTCK-SWCLK
PA2.Signal=S_TIM5_CH3
PA3.Signal=S_TIM5_CH4
PA6.Signal=S_TIM3_CH1
PB0.Signal=S_TIM3_CH3
PB1.Signal=S_TIM3_CH4
PB3.Signal=SYS_JTDO-TRACESWO
PC6.Signal=S_TIM8_CH1
PD0-OSC_IN.Signal=RCC_OSC_IN
PD1-OSC_OUT.Signal=RCC_OSC_OUT

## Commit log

2025-04-30 Adding STM32F1 nucleo board working code for one LED strip
2025-04-30 Created new PCB files and added KiCAD gitignore config
    [LED-DriverPCB.kicad_pcb, LED-DriverPCB.kicad_sch]
2025-05-08 Picked out MCU and added it to schematic
    [LED-DriverPCB.kicad_sch]
2025-05-08 Adding STM32CubeIDE files
2025-05-10 Finished MCU connections
    [LED-DriverPCB.kicad_sch]
2025-06-02 Finished schematic
    [LED-DriverPCB.kicad_sch]
2025-06-02 Added footprints
    [026013114.stp, 039303037.stp, LED-DriverPCB.kicad_sch]
2025-06-02 Worked on PCB layout
    [HRO_TYPE-C-31-M-12.step, LED-DriverPCB.kicad_pcb, LED-DriverPCB.kicad_sch]
2025-06-03 Rough layout completed
    [LED-DriverPCB.kicad_pcb]
2025-06-09 Finished edge cuts
    [LED-DriverPCB.kicad_pcb, LED-DriverPCB.kicad_sch]
2025-06-09 Placed parts
    [LED-DriverPCB.kicad_pcb, LED-DriverPCB.kicad_sch]
2025-06-10 Small changes
    [LED-DriverPCB.kicad_pcb]
2025-06-11 Aligned connectors
    [LED-DriverPCB.kicad_pcb]
2025-06-11 Started routing
    [LED-DriverPCB.kicad_pcb, LED-DriverPCB.kicad_sch]
2025-06-14 More routing
    [LED-DriverPCB.kicad_pcb]
2025-06-18 Finalized layout
    [LED-DriverPCB.csv, LED-DriverPCB.kicad_pcb, LED-DriverPCB.kicad_sch]
2025-06-20 Finished PCB
    [LED-DriverPCB.kicad_pcb, LED-DriverPCB.kicad_sch]
2025-06-20 Created manufaturing files
    [LED-DriverPCB-B_Cu.gbr, LED-DriverPCB-B_Mask.gbr, LED-DriverPCB-B_Paste.gbr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]
2025-07-13 Added code to get LED strip 1 port to run pink bouncing light program. Has not been tested on LED strip - simply testing to see if I can upload code
2025-07-21 Refactored SK6812 driver to control multiple LED strips via a strip handle
2025-07-24 Changed MCU and level shifter
    [LED-DriverPCB.kicad_pcb, LED-DriverPCB.kicad_sch]
2025-07-24 Added schematic for new level shifter
    [LED-DriverPCB.kicad_sch]
2025-07-27 fixed bugs
    [LED-DriverPCB.kicad_pcb, LED-DriverPCB.kicad_sch]
2025-07-28 Fixed issues
    [LED-DriverPCB.kicad_pcb, LED-DriverPCB.kicad_sch]
2025-07-28 Added garage logo
    [LED-DriverPCB.kicad_pcb]
2025-07-28 Created manufacturing files
    [LED-DriverPCB-B_Cu.gbr, LED-DriverPCB-B_Mask.gbr, LED-DriverPCB-B_Paste.gbr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]
2025-08-08 Adding new Firmware project for PCB RevB
2025-08-09 Added LEDStrip Manager component to manage multiple led strips. Tested out driver atop car garage. 5/8 led strips working
2025-12-06 Added LED startup sequence
2025-12-06 Working LED usb control protocol with python script to test
2025-12-06 Added led control webpage
2025-12-07 Playing audio only when connected to stm32

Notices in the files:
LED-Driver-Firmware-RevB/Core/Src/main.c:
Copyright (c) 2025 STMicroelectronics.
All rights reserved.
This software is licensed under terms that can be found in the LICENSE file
